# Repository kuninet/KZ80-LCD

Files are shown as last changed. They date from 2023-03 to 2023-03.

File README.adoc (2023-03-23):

= LCD SC1603 BOARD for KZ80マイコン 

== 概要
* 16桁x2行のLCDモジュール SC1602をSBC8080バス(KZ80-CPUBとか)へ接続するボードです。

== 説明
* SBC8080バス(KZ80-CPUBとか)へ接続するボードです。
* 74HC138でI/Oアドレスデコードします。$80〜や$90〜に設定がおすすめ。

== I/Oアドレス($90〜の場合)
* I/Oアドレスを$90〜とした場合

|===
|I/Oアドレス|RD/WR|説明

|$90
|WR
|各種設定

|$91
|WR
|CG RAM、DDRAMへデータ書き込み

|$92
|RD
|Busyフラグ、CG RAM、DDRAMアドレス読み出し

|$93
|RD
|CG RAM、DDRAMからデータ読み出し

|===

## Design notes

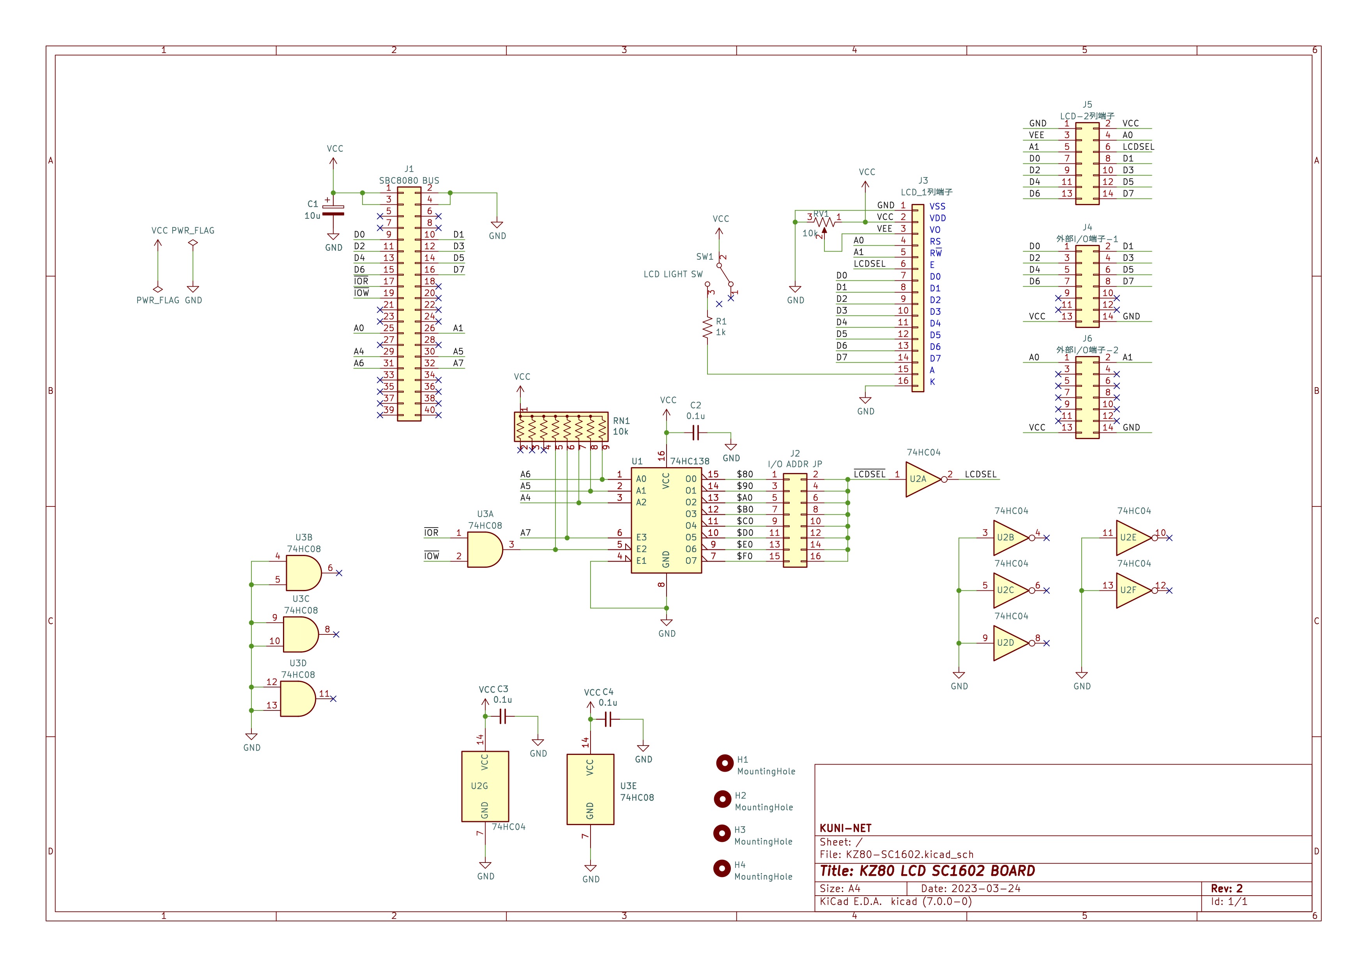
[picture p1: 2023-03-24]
image/KZ80-SC1602.jpg

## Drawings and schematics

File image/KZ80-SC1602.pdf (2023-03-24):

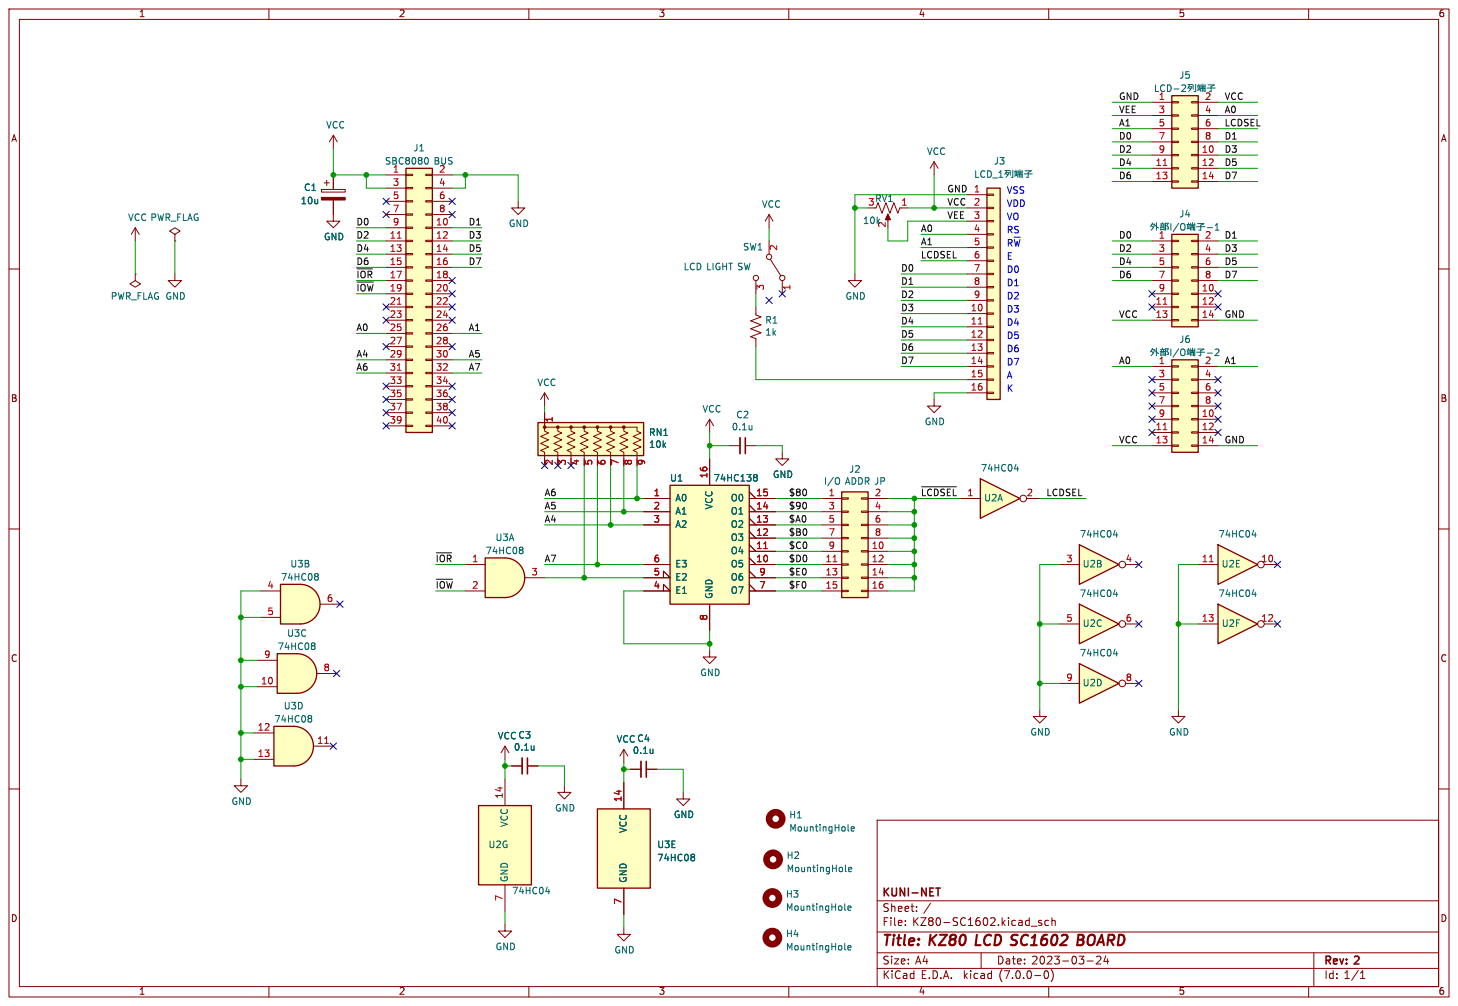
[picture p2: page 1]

H2 MountingHole H4 MountingHole H1 MountingHole H3 MountingHole

File: KZ80-SC1602.kicad_sch Sheet: / KUNI-NET

Id: 1/1 Title: KZ80 LCD SC1602 BOARD

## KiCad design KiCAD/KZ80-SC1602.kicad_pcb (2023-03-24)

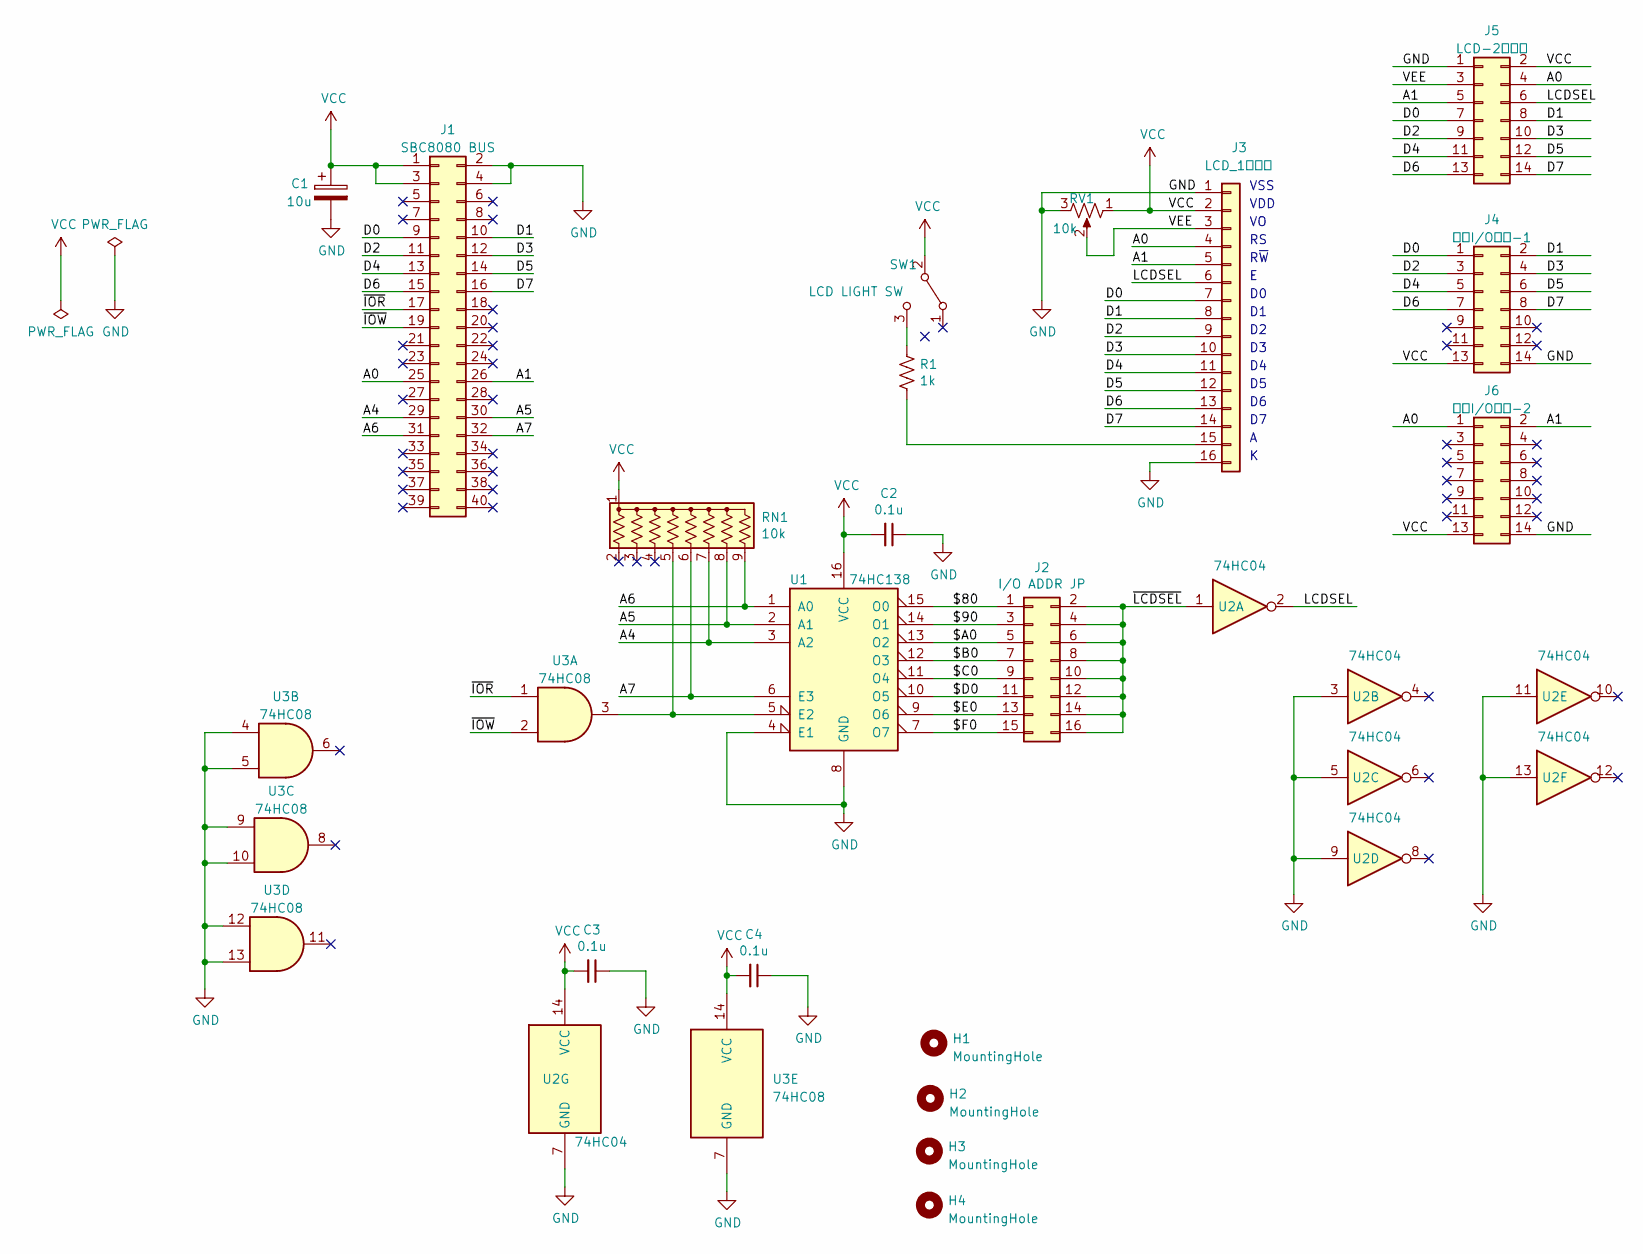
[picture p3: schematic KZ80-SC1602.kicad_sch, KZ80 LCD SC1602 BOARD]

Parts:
C1: 10u; CP_Radial_D5.0mm_P2.50mm
C2, C3, C4: 0.1u; C_Disc_D3.0mm_W1.6mm_P2.50mm
H1, H2, H3, H4: MountingHole; MountingHole_3.2mm_M3
J1: SBC8080 BUS; PinHeader_2x20_P2.54mm_Horizontal
J2: I/O ADDR JP; PinHeader_2x08_P2.54mm_Vertical
J3: LCD_1列端子; PinHeader_1x16_P2.54mm_Vertical
J4: 外部I/O端子-1; PinHeader_2x07_P2.54mm_Vertical
J5: LCD-2列端子; PinHeader_2x07_P2.54mm_Vertical
J6: 外部I/O端子-2; PinHeader_2x07_P2.54mm_Vertical
R1: 1k; R_Axial_DIN0207_L6.3mm_D2.5mm_P10.16mm_Horizontal
RN1: 10k; R_Array_SIP9
RV1: 10k; Potentiometer_Vishay_T73YP_Vertical
SW1: LCD LIGHT SW; PinHeader_1x03_P2.54mm_Vertical
U1: 74HC138; DIP-16_W7.62mm_Socket
U2: 74HC04; DIP-14_W7.62mm_Socket
U3: 74HC08; DIP-14_W7.62mm_Socket

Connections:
/$80: J2.1, U1.15 (O0)
/$90: J2.3, U1.14 (O1)
/$A0: J2.5, U1.13 (O2)
/$B0: J2.7, U1.12 (O3)
/$C0: J2.9, U1.11 (O4)
/$D0: J2.11, U1.10 (O5)
/$E0: J2.13, U1.9 (O6)
/$F0: J2.15, U1.7 (O7)
/A0: J1.25, J3.4, J5.4, J6.1
/A1: J1.26, J3.5, J5.5, J6.2
/A4: J1.29, RN1.7 (R6), U1.3 (A2)
/A5: J1.30, RN1.8 (R7), U1.2 (A1)
/A6: J1.31, RN1.9 (R8), U1.1 (A0)
/A7: J1.32, RN1.6 (R5), U1.6 (E3)
/D0: J1.9, J3.7, J4.1, J5.7
/D1: J1.10, J3.8, J4.2, J5.8
/D2: J1.11, J3.9, J4.3, J5.9
/D3: J1.12, J3.10, J4.4, J5.10
/D4: J1.13, J3.11, J4.5, J5.11
/D5: J1.14, J3.12, J4.6, J5.12
/D6: J1.15, J3.13, J4.7, J5.13
/D7: J1.16, J3.14, J4.8, J5.14
/LCDSEL: J3.6, J5.6, U2.2
/VEE: J3.3, J5.3, RV1.2
/~IOR: J1.17, U3.1
/~IOW: J1.19, U3.2
/~LCDSEL: J2.2, J2.4, J2.6, J2.8, J2.10, J2.12, J2.14, J2.16, U2.1
GND: C1.2, C2.1, C3.1, C4.1, J1.2, J1.4, J3.1, J3.16, J4.14, J5.1, J6.14, RV1.3, U1.4 (E1), U1.8 (GND), U2.3, U2.5, U2.7 (GND), U2.9, U2.11, U2.13, U3.4, U3.5, U3.7 (GND), U3.9, U3.10, U3.12, U3.13
unnamed: J3.15, R1.2
unnamed: RN1.5 (R4), U1.5 (E2), U3.3
unnamed: R1.1, SW1.3 (C)
VCC: C1.1, C2.2, C3.2, C4.2, J1.1, J1.3, J3.2, J4.13, J5.2, J6.13, RN1.1 (common), RV1.1, SW1.2 (B), U1.16 (VCC), U2.14 (VCC), U3.14 (VCC)

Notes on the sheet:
VSS
VDD
R~{W}

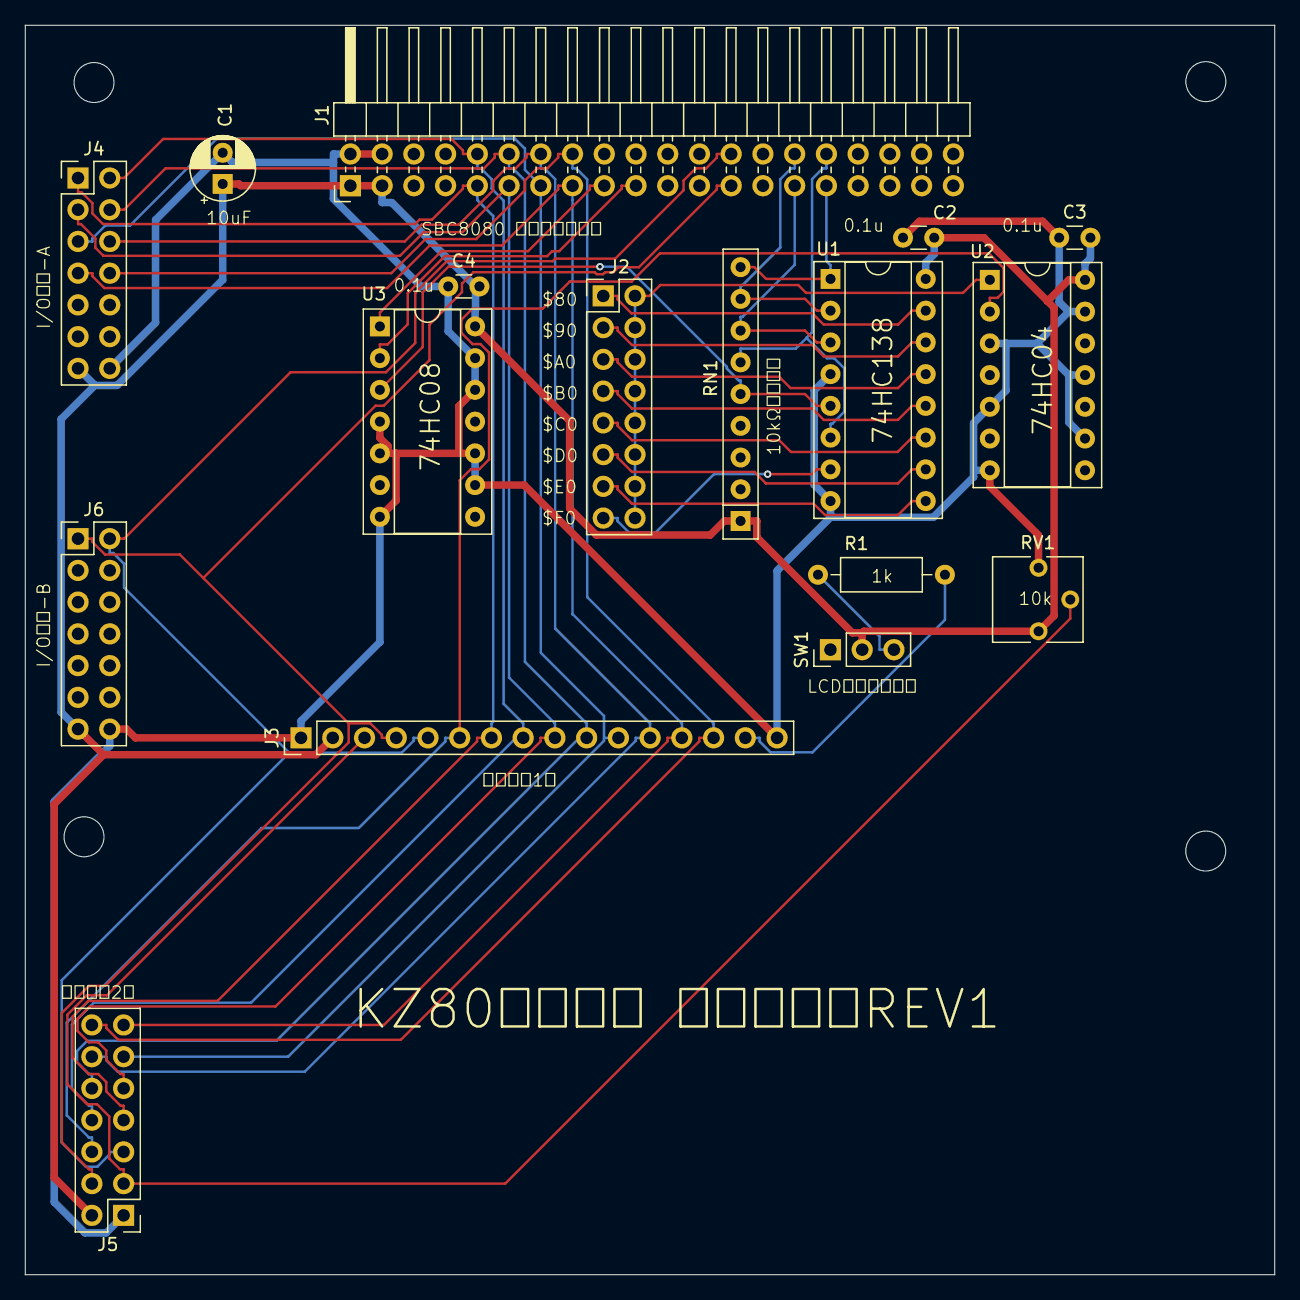
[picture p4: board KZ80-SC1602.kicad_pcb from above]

Board: 2 copper layers, 100.0 x 100.0 mm, 21 parts (0 on the bottom side), 32 nets.

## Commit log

2023-03-24 REV1基板ガーバーデータ出力
    [KZ80-SC1602.dsn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]
2023-04-08 LCD表示テストプログラム追加
